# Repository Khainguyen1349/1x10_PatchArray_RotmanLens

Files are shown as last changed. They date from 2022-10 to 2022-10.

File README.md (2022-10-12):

# Phased array patch antenna @10GHz

Objective: “Design a 1D patch phased array of 10 elements with corporate feeding network for broadside radiation, target return loss is -10 dB. Calculate the radiation pattern analytically and numerically and compare them. If you want you can select the operating frequency yourself, otherwise use 10 GHz.”

Detail report can be found in https://github.com/Khainguyen1349/1x10_PatchArray_RotmanLens/blob/main/Phased%20array%20patch%20antenna%20%4010GHz.pdf

The analytical analysis is done in https://github.com/Khainguyen1349/1x10_PatchArray_RotmanLens/blob/main/Main.m

The final design is as following

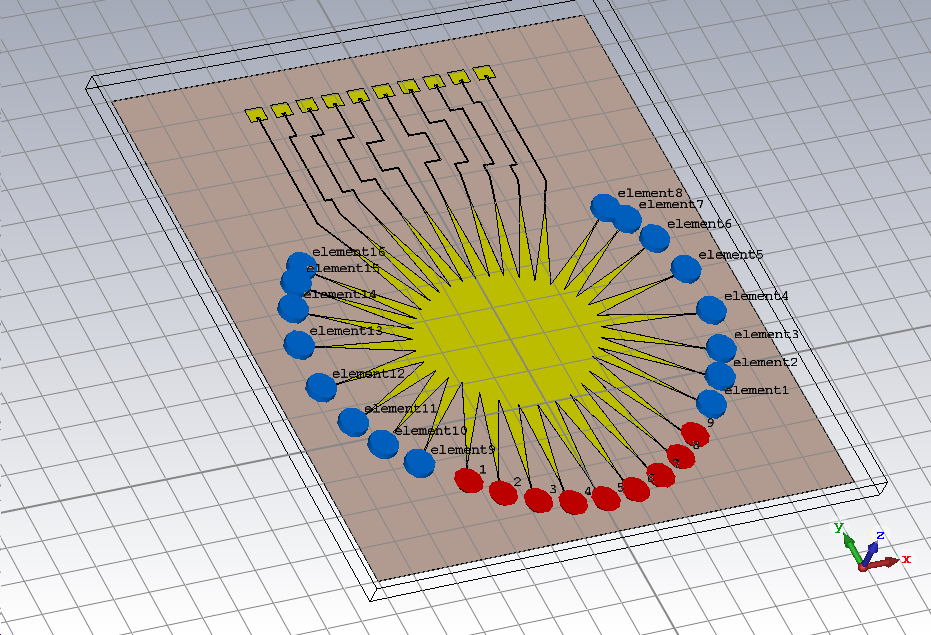
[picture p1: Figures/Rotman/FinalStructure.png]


By principle, each port of the Rotman lens excites different phase-shift to the antenne 

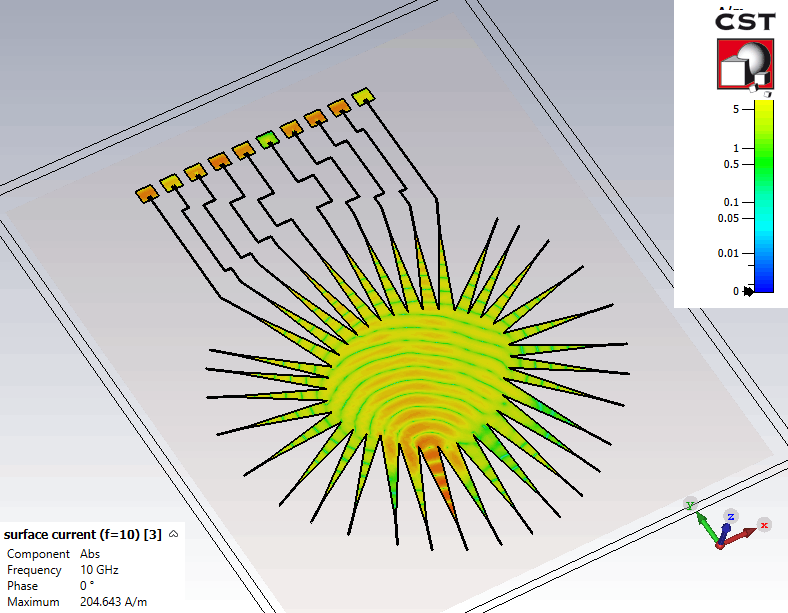
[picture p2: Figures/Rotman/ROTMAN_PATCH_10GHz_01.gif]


By feeding different ports, we can have these scanning beams covering 60 degrees

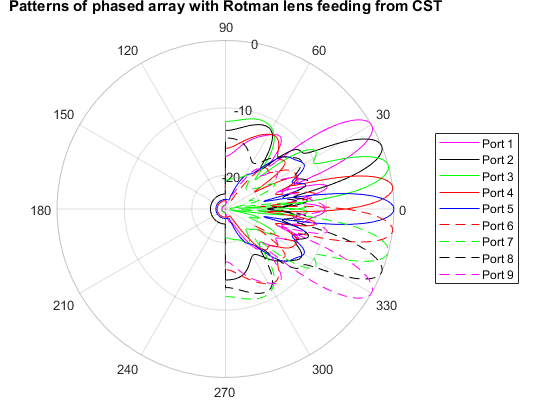
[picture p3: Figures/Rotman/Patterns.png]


3D pattern

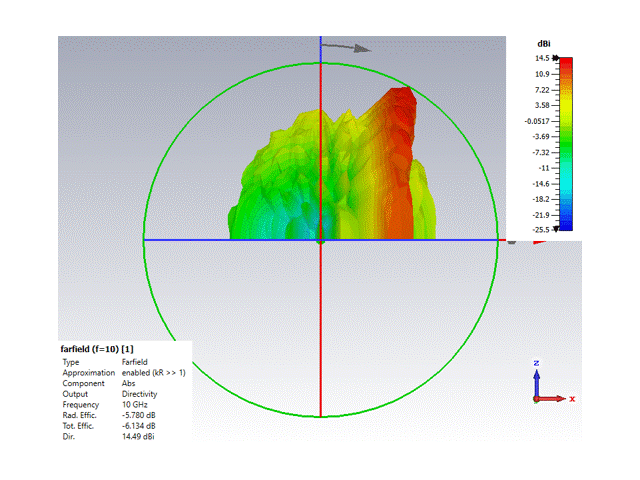
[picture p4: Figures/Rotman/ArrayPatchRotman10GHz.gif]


The design have a better impedance matching than -10dB and total loss lower than 5.5dB.

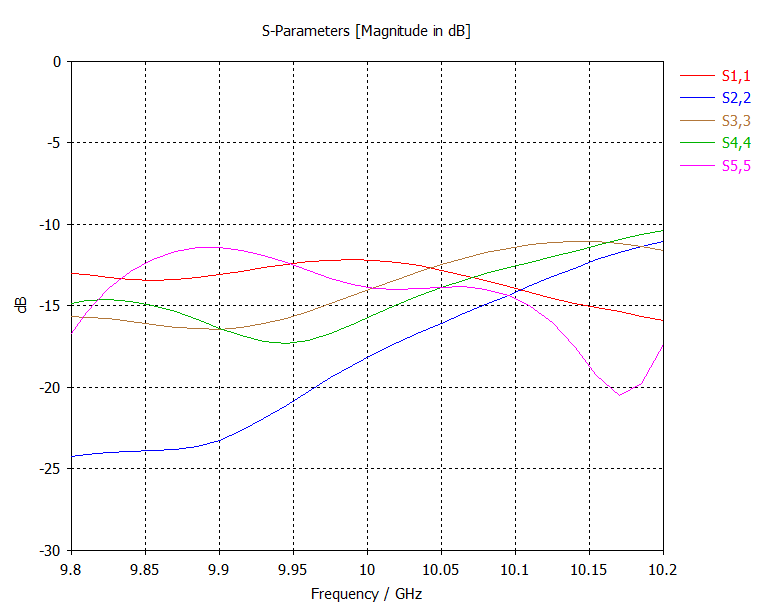
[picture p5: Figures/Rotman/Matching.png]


References

1. Eurocircuits site: https://www.eurocircuits.com/ 

2. Balanis, “Antenna Theory: Analysis and Design,” 4th edition, MATLAB code: https://fr.mathworks.com/academia/books/antenna-theory-balanis.html 

3. Rotman lens design using MATLAB: https://fr.mathworks.com/matlabcentral/fileexchange/50490-rotman-lens-design-with-hfss-link?s_tid=mwa_osa_a 
 
4. Patch dimension calculator: https://www.pasternack.com/t-calculator-microstrip-ant.aspx 

5. Microstrip line calculator: https://www.pasternack.com/t-calculator-microstrip.aspx

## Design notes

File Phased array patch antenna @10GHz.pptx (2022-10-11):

## Phased array patch antenna @10GHz

Objective: “Design a 1D patch phased array of 10 elements with corporate feeding network for broadside radiation, target return loss is -10 dB. Calculate the radiation pattern analytically and numerically and compare them. If you want you can select the operating frequency yourself, otherwise use 10 GHz.”

## Stack-up

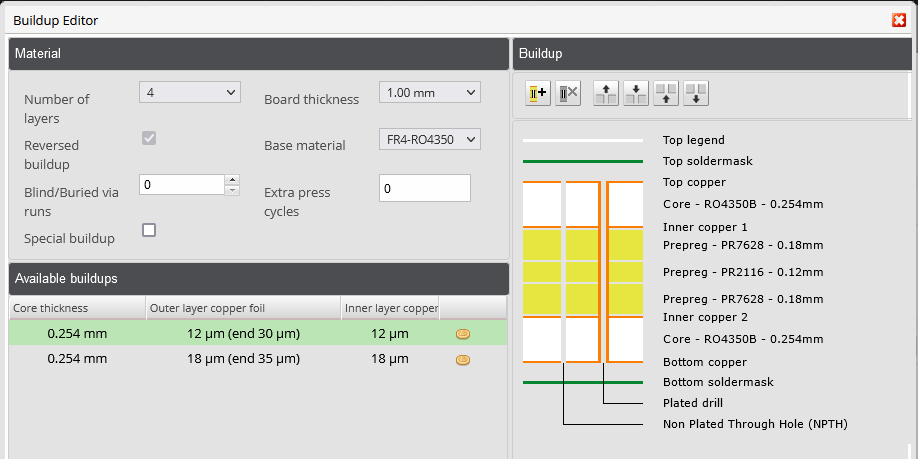
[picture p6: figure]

- Find an industrialized stack-up so that the design can be fabricated.
- 4-layer stack-up allows having thin substrate, hence thin feeding microstrip line.
- RO4350B chosen for lower dielectric loss

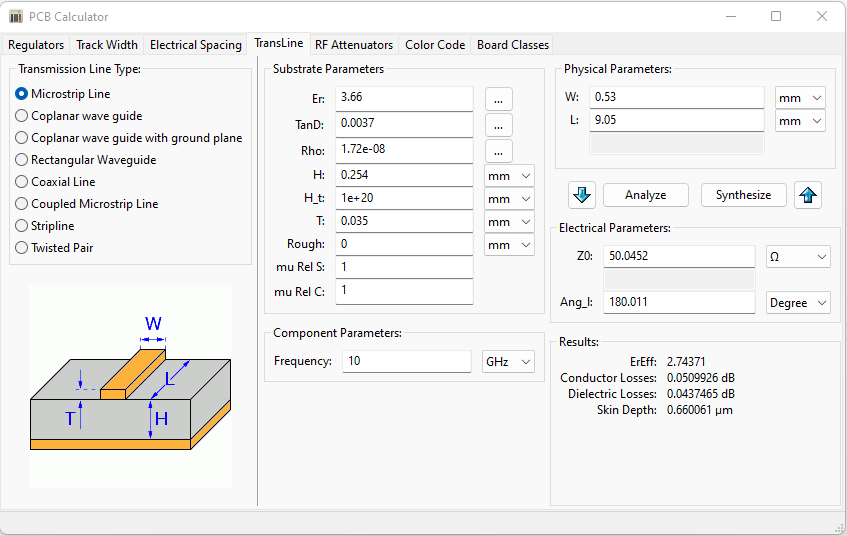
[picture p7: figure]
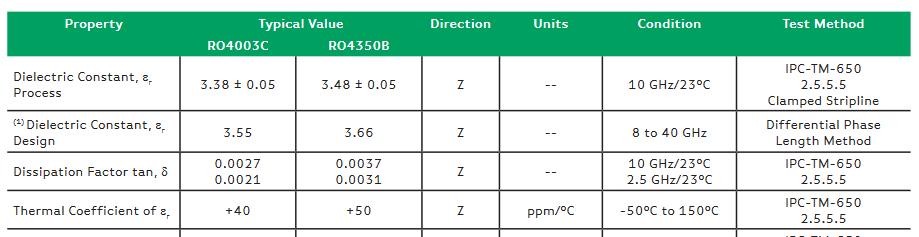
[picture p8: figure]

## Intended design

- The patch array antenna is designed as follow:
  - Broadside direction toward +Z
  - Feeding comes from –Y toward +Y
  - Array’s elements placed 1D along X and have distance (λ_0)/2

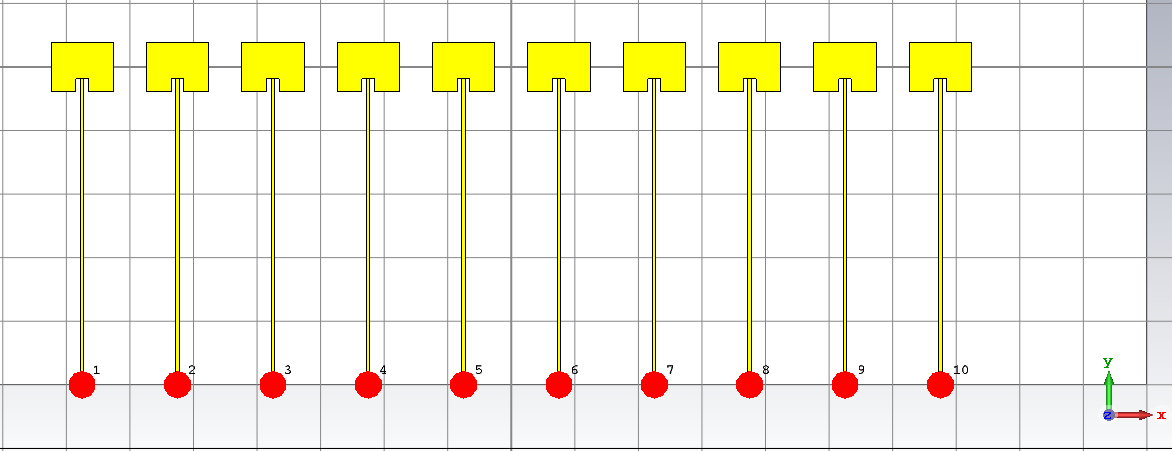
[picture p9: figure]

## Analytical estimation of 1x10 patch array

## Analytical analysis of the array

- Cavity model of the element patch antenna
- TM010 as dominant mode
- The following is MATLAB calculation from Balanis for the intended design (chapter 14)

INPUT PARAMETERS
================
RESONANT FREQUENCY (in GHz) = 10.0000
DIELECTRIC CONSTANT OF THE SUBSTRATE = 3.6600
HEIGHT OF THE SUBSTRATE (in cm) = 0.0254
POSITION OF THE RECESSED FEED POINT (in cm) = 0.2000
OUTPUT PARAMETERS
=================
PHYSICAL WIDTH OF PATCH (in cm) = 0.9827
EFFECTIVE LENGH OF PATCH (in cm) = 0.8027
PHYSICAL LENGH OF PATCH (in cm) = 0.7785
E-PLANE HPBW (in degrees) = 136.0000
H-PLANE HPBW (in degrees) = 80.0000
DIRECTIVITY OF RECTANGULAR PATCH (dimensionless) = 4.2200
DIRECTIVITY OF RECTANGULAR PATCH (in dB) = 6.2531
RESONANT INPUT RESISTANCE AT LEADING RADIATING EDGE (y=0) Rin0= 293.4669 ohms
RESONANT INPUT RESISTANCE AT RECESSED FEED POINT (y=0.2000 cm) RINYo= 140.3699 ohms
*** NOTE:
THE E-PLANE AMPLITUDE PATTERN IS STORED IN Epl-Micr_m.dat
THE H-PLANE AMPLITUDE PATTERN IS STORED IN Hpl-Micr_m.dat
=========================================================

## Analytical analysis of the array

E-plane ( θ=90^o )

H-plane ( φ=0^o )

- Analytical pattern calculated by Balanis for X-direction broadside
- E-plane ( θ=90^o )
- H-plane( φ=0^o )

## Analytical analysis of the array

E-plane ( φ=90^o )

H-plane ( φ=0^o )

θ

- The symmetry of the antenna allows us to have now
  - E-plane ( θ=90^o )
  - H-plane( θ=0^o )
- Rotating 90^o along Y-axis to achieve the intended +Z broadside patch antenna.

## Analytical analysis of the array

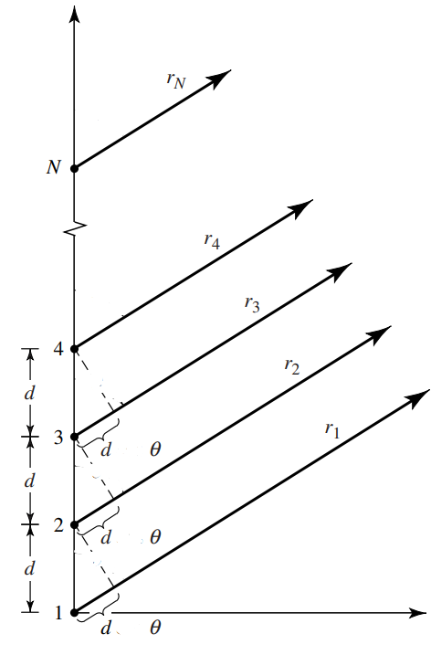
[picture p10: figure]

x

- Array factor of the 1×10 patch array along X axis
- Broadside direction is along +Z
- AF=1/N(1+e^(j(kdsinθ+β)) +…+e^(+j2(kdsinθ+β)) +e^(+j9(kdsinθ+β)) )=1/N[(sin⁡(N/2(kdsinθ+β)))/(sin⁡(((kdsinθ+β))/2))]
with N=10, d=15mm,k=(2π)/λ , and β is phase difference between neighbor elements.
- So
E_(φ_arr) =AF×E_φ

sin⁡

sin⁡

sin⁡

θ

z

## Analytical analysis of the array

β=0^o

β=30^o

β=60^o

## Numerical estimation of 1x10 patch array

## Patch array design

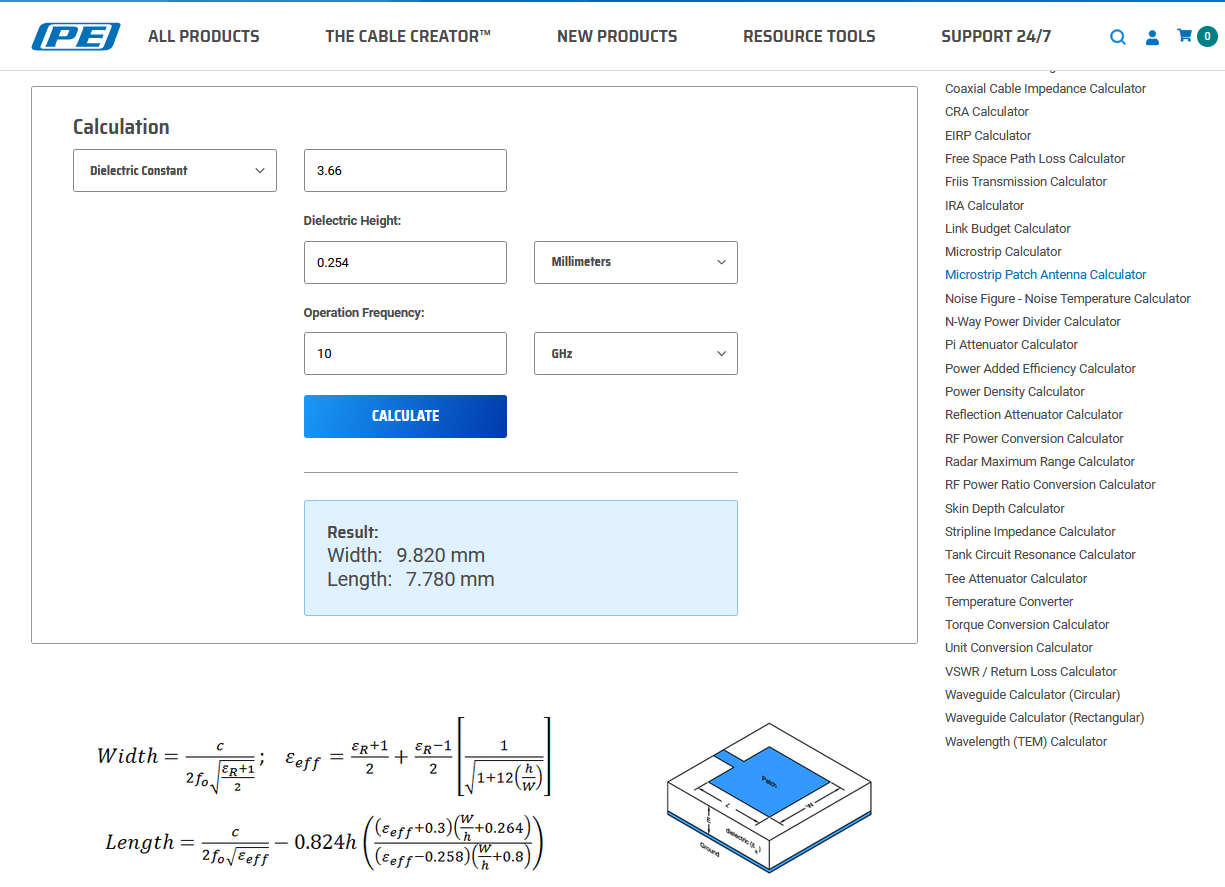
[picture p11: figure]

- Using online tool to calculate patch dimension.

## Numerical simulation CST

- Recessed microstrip-line feed point to have a better impedance matching
- Making array with distance λ_(air) /2 = 15mm and with separate ports
- Phase excitation is controlled by simulator
- Microstrip line width is 0.53mm

2mm

7.75mm

9.82mm

2mm

Single patch design

1x10 patch array design

## Numerical simulation CST

- Simulation of single patch

2mm

7.75mm

9.82mm

2mm

Single patch design

3D radiation pattern of single patch

Impedance matching of single patch

## Numerical simulation CST

- Simulation of single patch

2mm

7.75mm

9.82mm

2mm

Single patch design

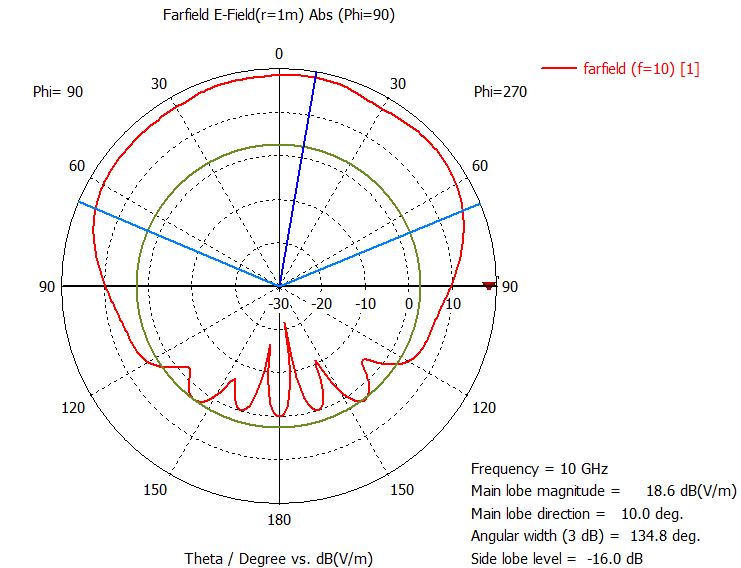
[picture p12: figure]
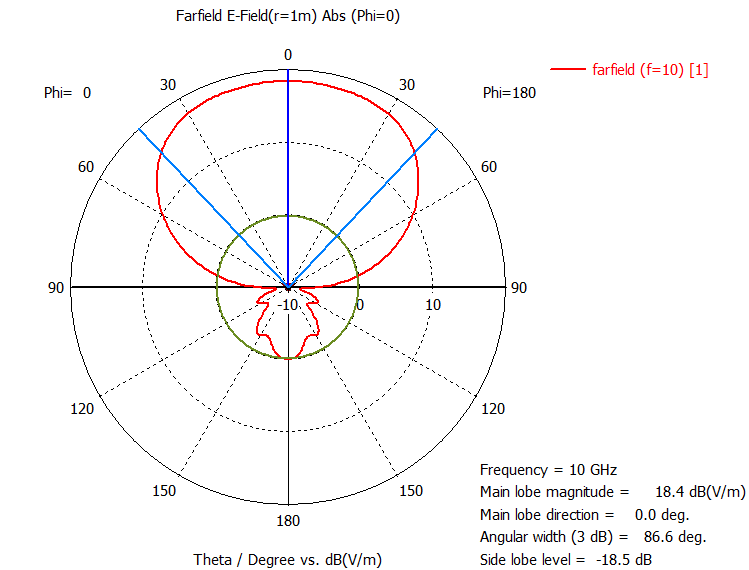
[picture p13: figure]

E-plane

H-plane

## Numerical simulation CST

- Simulation of single patch versus analytical results
  - Directivity = 6.62 dBi (versus 6.25 dBi of analytical result)
  - E-plane HPBW = 134.8o (versus 136o of analytical result)
  - H-plane HPBW = 86.6o (versus 80o of analytical result)

2mm

7.75mm

9.82mm

2mm

Single patch design

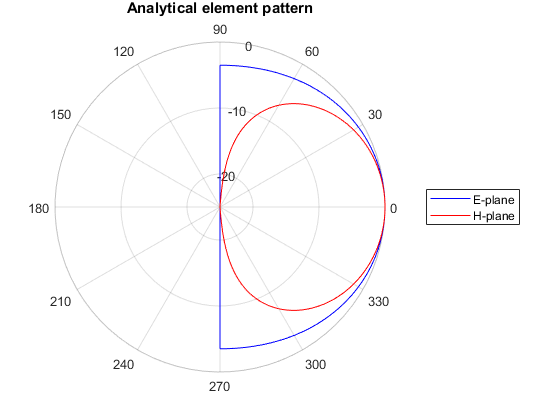
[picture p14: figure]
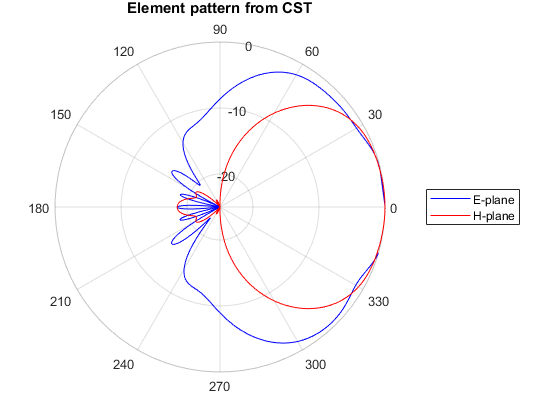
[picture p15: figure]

*back radiation due to finite ground plane

## Numerical simulation CST

- Simulation of 1x10 patch array ( β=0^o )

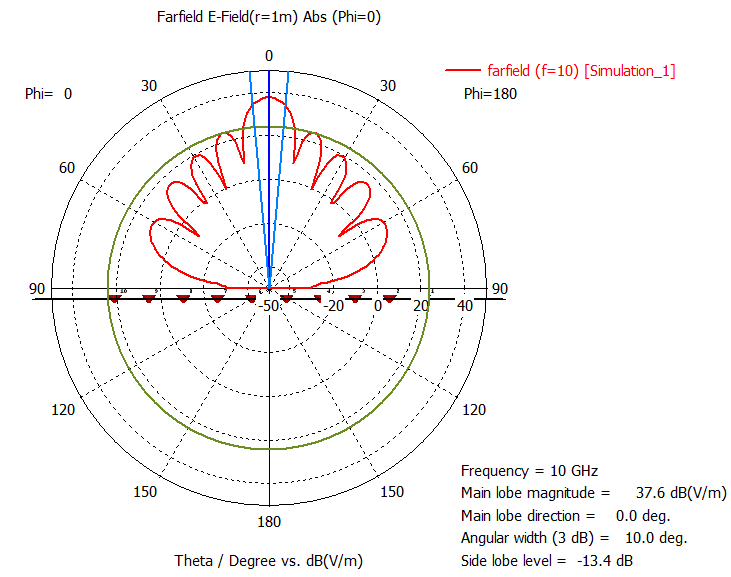
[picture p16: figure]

Array directivity

E-plane

H-plane

## Numerical simulation CST

- Simulation of 1x10 patch array ( β=30^o )

Array directivity

E-plane

H-plane

## Numerical simulation CST

- Simulation of 1x10 patch array ( β=60^o )

E-plane

H-plane

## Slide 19

Full analytical result from MATLAB calculations of patch pattern and array factor
- Main lobe at 0^o
- Beamwidth ~10^o
- Directivity 16.2 dBi

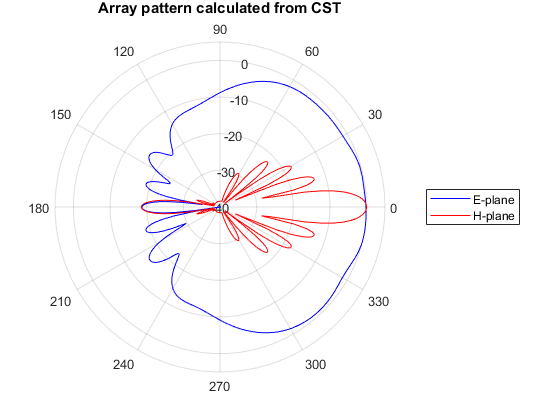
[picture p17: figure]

Partially analytical result from numerical patch pattern and MATLAB calculation array factor
- Close to full analytical results

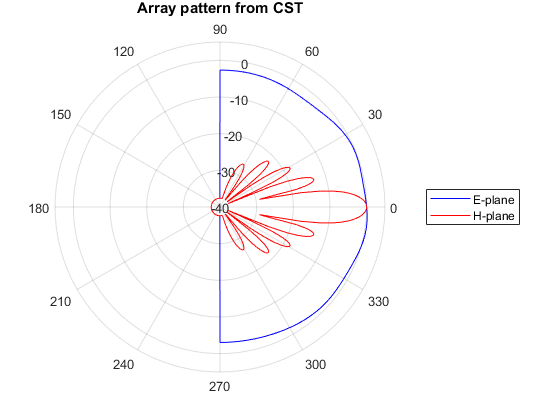
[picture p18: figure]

Full numerical result of the array. Electric boundary is used as ground so there is no back radiation
- Main lobe at 0^o
- Beamwidth ~10^o
- Directivity 14.8 dBi

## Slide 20

Full analytical result
- Main lobe at 10^o
- Beamwidth ~10^o
- Directivity 16.2 dBi

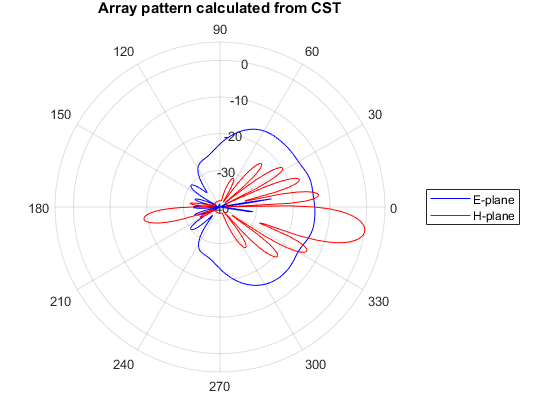
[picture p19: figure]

Partially analytical result
- Close to full analytical results

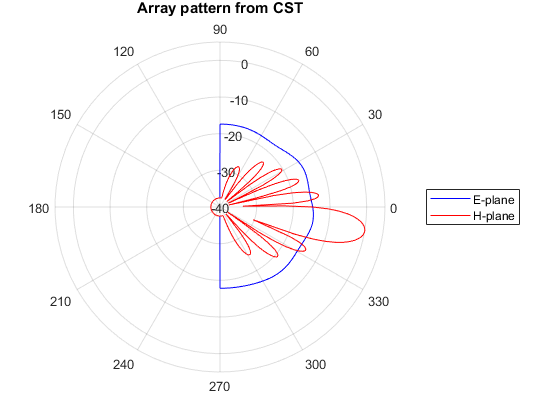
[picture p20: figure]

Full numerical result
- Main lobe at 9^o
- Beamwidth ~10^o
- Directivity 14.7 dBi

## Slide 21

Full analytical result
- Main lobe at 20^o
- Beamwidth ~10^o
- Directivity 16.2 dBi

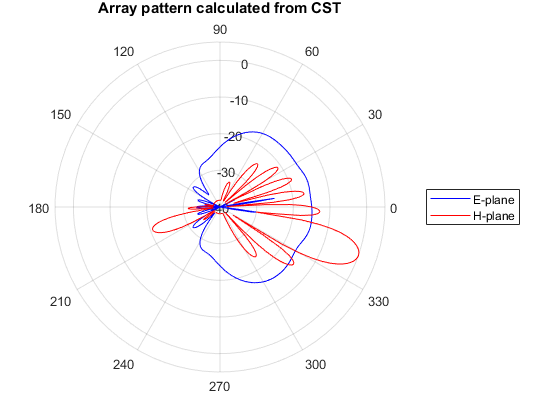
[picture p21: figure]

Partially analytical result
- Close to full analytical results

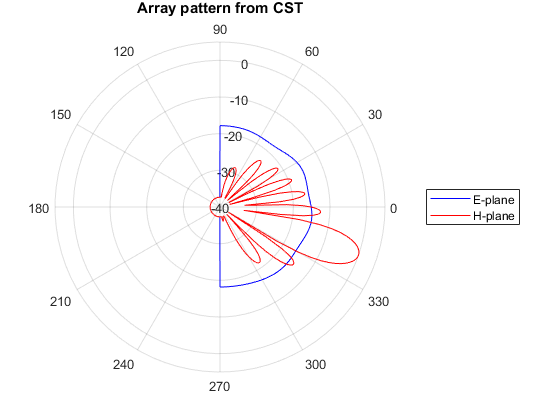
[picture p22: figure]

Full numerical result
- Main lobe at 19^o
- Beamwidth ~10^o
- Directivity 14.8 dBi

## Conclusion

- The numerical results of separating-element array are quite close to either full or partial analytical results if we ignore the back radiation (depends on ground plane side), in terms of
  - Direction of main lobe
  - Direction and number of nulls
  - Beamwidth
  - Directivity
- The asymmetry of the feed, the finite dimension of the ground in simulation can introduce some differences in the single element pattern and hence array pattern.

## Design of feeding network

## Feeding network

- To produce the difference in phase excitation of each element of the array we can
  - Use some active components, such as phase-shifter.
    - Normally requires complicated control.
    - Need to design a DC part that doesn’t couple with RF part
  - Passive feeding network, like
    - Butler matrix, need power-two (2^x) number of input and output
    - Rotman lens allows have any number of antenna port.

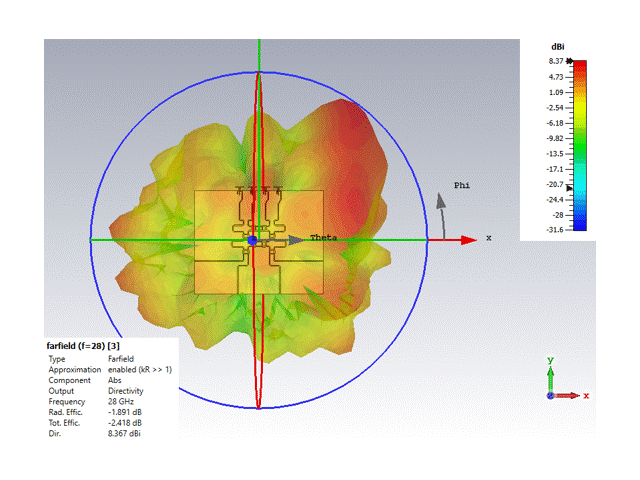
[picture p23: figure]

## Rotman lens for feeding network

- 10 array ports (connect to antennas)
- 9 beam ports (excitation ports)
- 8 dummy ports ( 50Ω loads)
- 30o phase shift

## ROTMAN import CST

- Phase differences are not perfectly produced as intended by the Rotman lens
  - Excitation of port 5: ~0^o
  - Excitation of port 4 and 6: ~30^o
  - Excitation of port 3 and 7: ~50^o
  - …
- All ports have better Return Loss than -12dB
- Expecting up to 6dB loss due to the Rotman lens

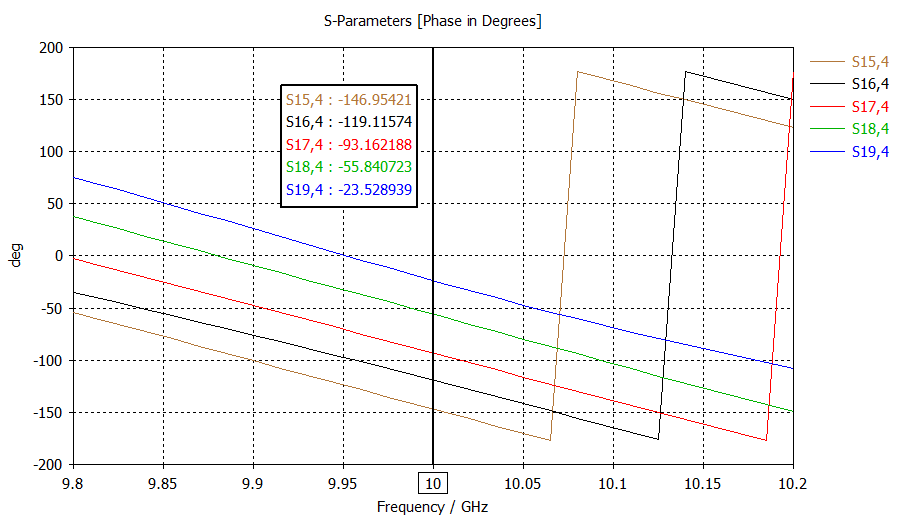
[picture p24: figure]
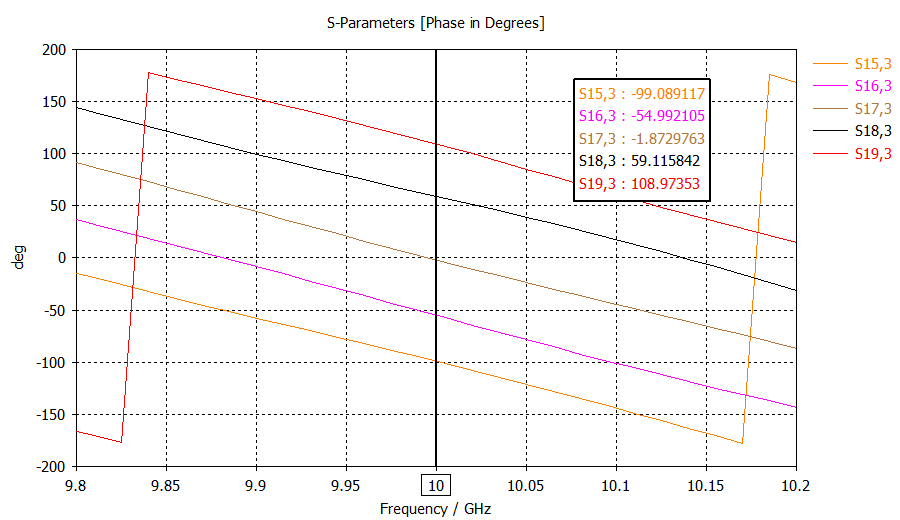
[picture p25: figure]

## Final design


- Some microstrip line phase-shifters are introduced and optimized to produce a phase balance at every antenna port.
- Simulation takes long time on a 16Gb RAM laptop and cannot run very fine meshes.

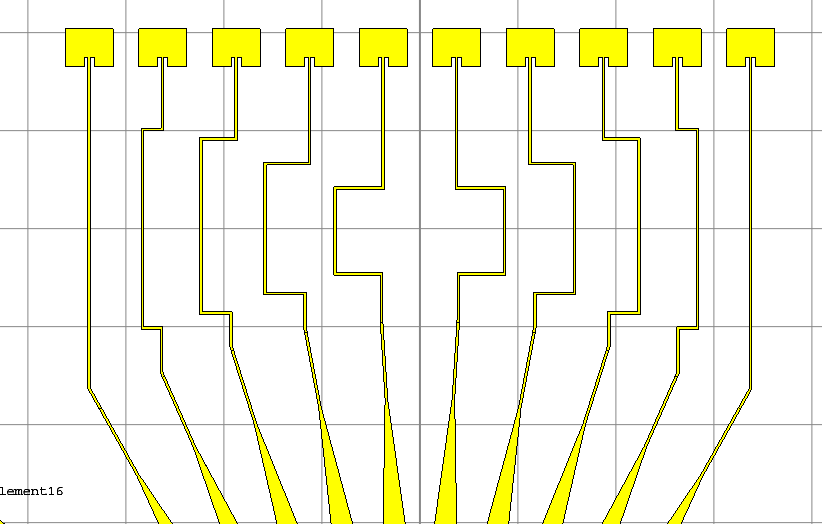
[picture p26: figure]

## Results

Excitation to Port 5 (in the middle)
- Main lobe at 0^o
- Beamwidth ~10^o
- Directivity 14.24 dBi

Excitation to Port 4
- Main lobe at 7^o
- Beamwidth ~10^o
- Directivity 14.07 dBi

Excitation to Port 3
- Main lobe at 15^o
- Beamwidth ~10^o
- Directivity 14.42 dBi

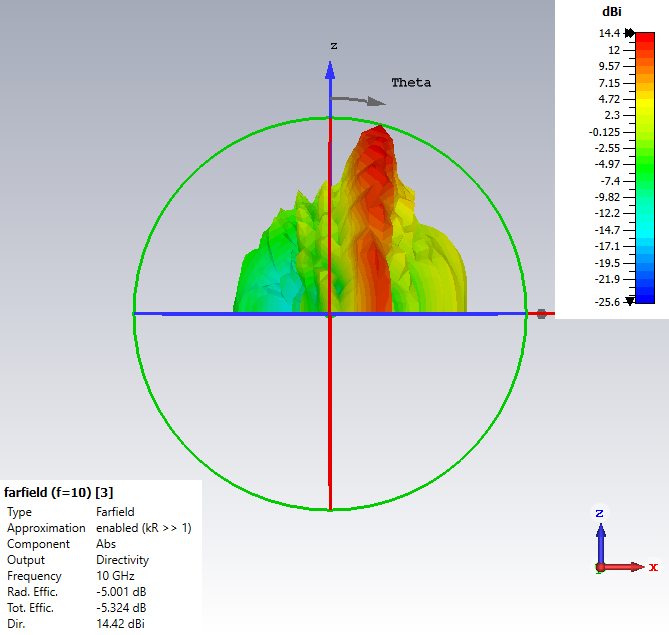
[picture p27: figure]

## Results

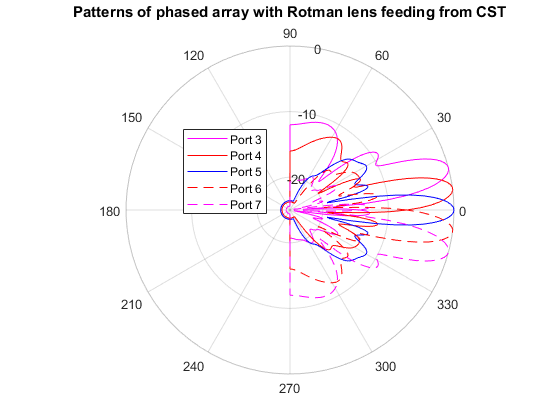
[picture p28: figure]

- Directivity and HPBW of the final design are similar to that of analytical and separating element design.
- Phase difference is smaller and varying making the angle of the main lobe smaller.
- Because the feeding network is not perfect, the pattern is not clean as the analytical synthesis or numerical result in which there is no feeding network.

## Perspective

- This is a preliminary design, refinements are required on
  - Fine mesh simulations
  - Optimizing the Rotman lens to obtain Δ30^o step
  - Optimizing the microstrip phase-shifters
  - Finalize the feeding ports to SMA

## References

1. Eurocircuits site: https://www.eurocircuits.com/
2. Balanis, “Antenna Theory: Analysis and Design,” 4th edition, MATLAB code: https://fr.mathworks.com/academia/books/antenna-theory-balanis.html
3. Rotman lens design using MATLAB: https://fr.mathworks.com/matlabcentral/fileexchange/50490-rotman-lens-design-with-hfss-link?s_tid=mwa_osa_a
4. Patch dimension calculator: https://www.pasternack.com/t-calculator-microstrip-ant.aspx
5. Microstrip line calculator: https://www.pasternack.com/t-calculator-microstrip.aspx

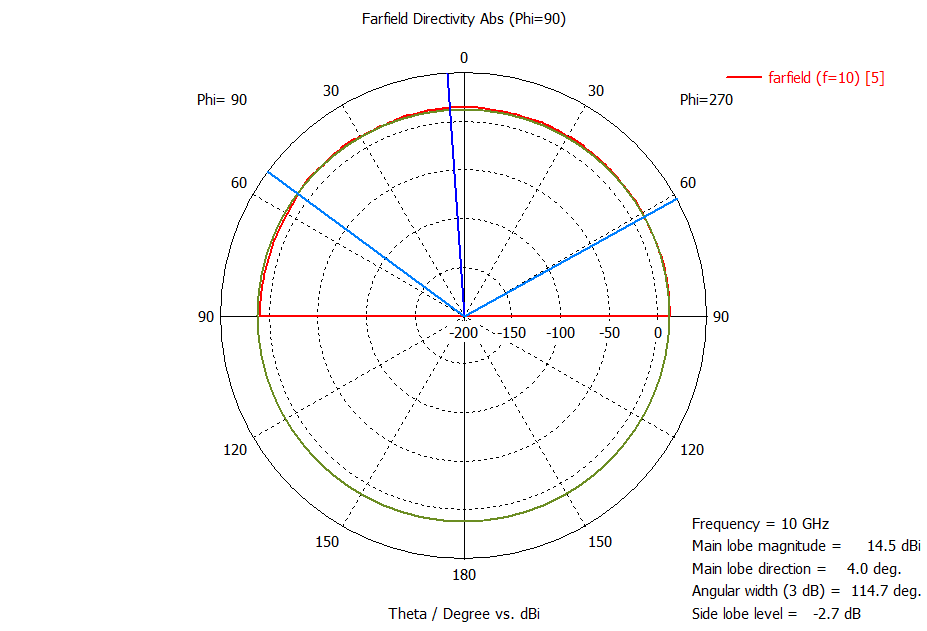
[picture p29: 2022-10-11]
Figures/Rotman/AF0degEplane.png

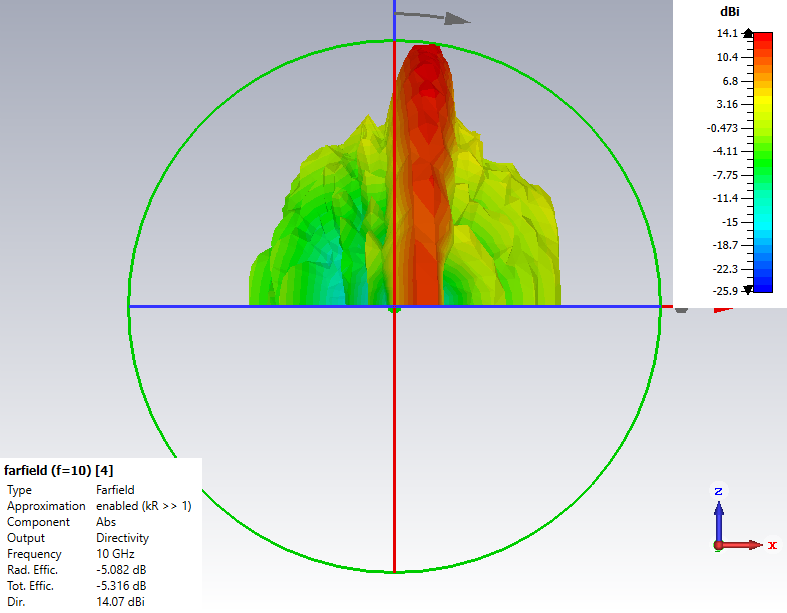
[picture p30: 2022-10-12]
Figures/Rotman/Port4.png

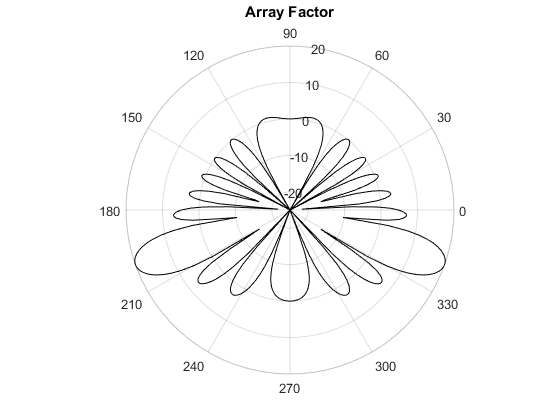
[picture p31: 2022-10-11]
Figures/AF60deg/ArrayFactor.png

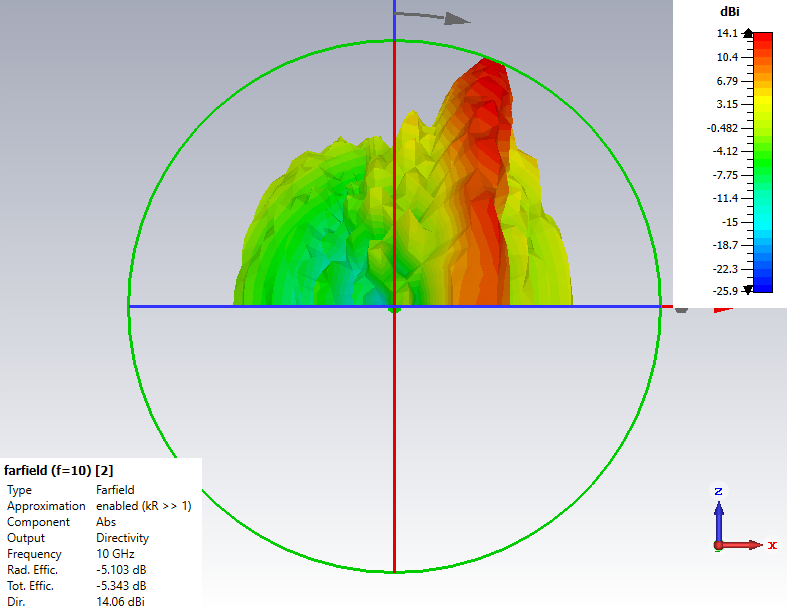
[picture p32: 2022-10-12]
Figures/Rotman/Port2.png

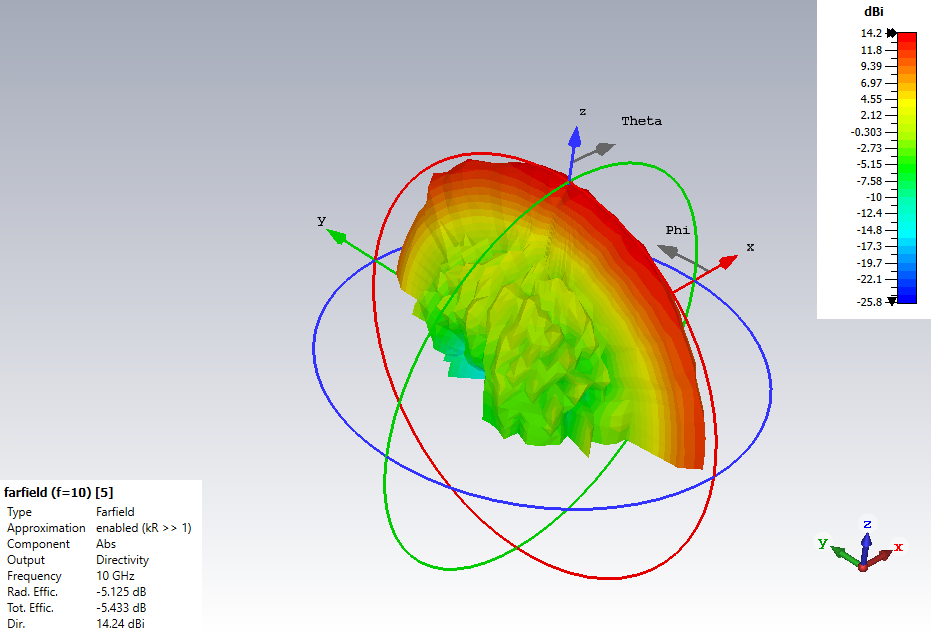
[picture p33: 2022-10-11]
Figures/Rotman/AF0deg.png

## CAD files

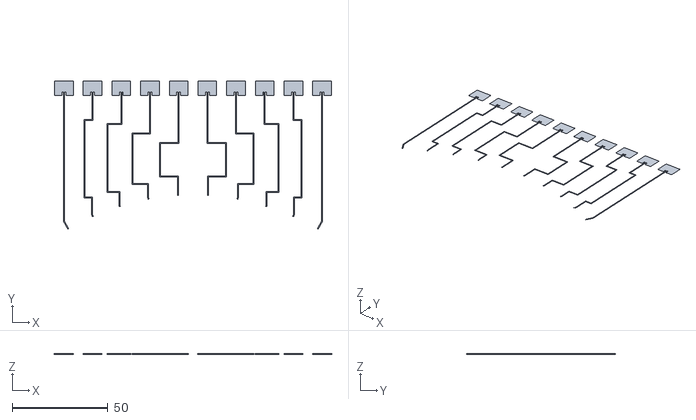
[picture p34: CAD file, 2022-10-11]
3D/PatchArray.stl
144.8 x 77.5 x 0.035

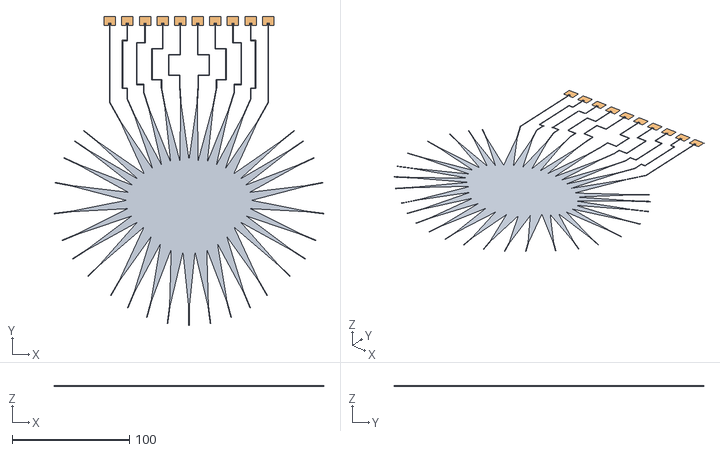
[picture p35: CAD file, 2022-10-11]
3D/Rotman.stl
230.1 x 263.4 x 0.035
Copper:Lens
Antenna:Patch
